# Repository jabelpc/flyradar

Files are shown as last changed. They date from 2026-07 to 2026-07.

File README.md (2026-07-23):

# 📡 FlyRadar

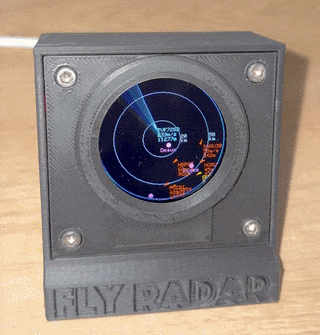
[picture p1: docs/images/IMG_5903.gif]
FlyRadar GIF


FlyRadar est un fork du projet micro-radar d'AnthonySturdy (https://github.com/AnthonySturdy/micro-radar). J'ai adapté le projet au matériel dont je disposais et ajouté des options de personnalisation ainsi qu'une mise à jour du firmware par OTA (téléversement over-the-air).

## Matériel

Le projet fonctionne avec un ESP32-C3 (super-mini) et un écran LCD 1,28" (GC9A01). Selon votre montage, quelques fils devront être soudés ou connectés avec des câbles Dupont.

Pour le boîtier, j'ai imprimé les pièces en PLA. L'écran et la carte sont fixés à la colle chaude ; des vis M3x15 peuvent être ajoutées pour la finition.

### Outils nécessaires

- Clé Allen 2,5 mm
- Pistolet à colle chaude
- Fer à souder (si vous choisissez l'option soudure)

Attention : l'écran est fragile et sensible aux rayures.

### Liste de composants (exemples)

- Écran 1.28" Round GC9A01 (IPS)
- Carte ESP32-C3 (super-mini)
- 4 vis M3x15

Toute carte ESP32 peut convenir, mais le câblage peut différer selon le modèle et doit être adapté.

### Câblage (exemple)

ESP32-C3 // LCD GC9A01

- 3V3 → VCC
- GND → GND
- GPIO4 → SCL
- GPIO5 → SDA
- GPIO9 → DC
- GPIO6 → CS
- GPIO3 → RST

<p align="center">
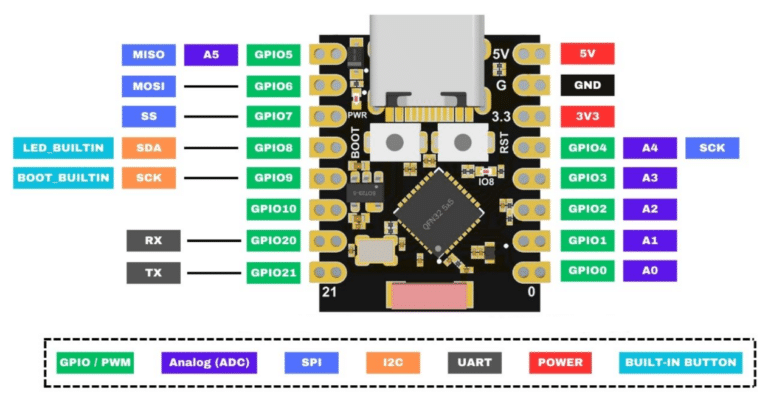
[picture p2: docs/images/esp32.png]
  
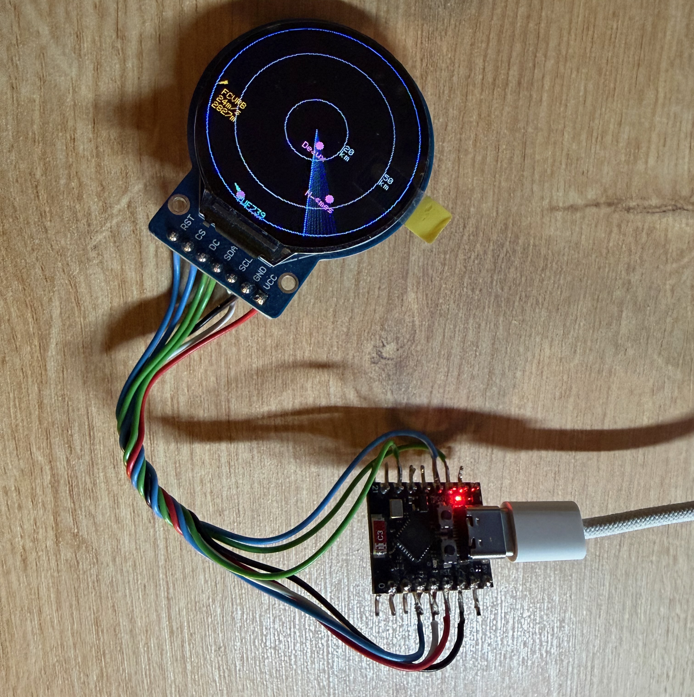
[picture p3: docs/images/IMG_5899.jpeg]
  
</p>

## Comptes / API

Ce projet peut utiliser l'API OpenSky pour récupérer les données de vol. Créer un compte OpenSky est recommandé (gratuit) : le quota de requêtes passe d'environ 400 à ~4000 par jour, améliorant la précision et la réactivité de l'affichage en direct. Inscrivez-vous sur https://opensky-network.org.

## Développement et téléversement

Installez Visual Studio Code et l'extension PlatformIO IDE. Ouvrez le projet dans VS Code ; PlatformIO installera automatiquement les dépendances.

Branchez la carte via USB-C et téléversez depuis PlatformIO (bouton Upload). Si la carte ne redémarre pas automatiquement, maintenez `BOOT`, appuyez sur `RESET`, puis relâchez `BOOT`.

## Premier démarrage

Au premier démarrage, la carte diffuse un point d'accès Wi‑Fi `FlyRadar-Setup`. Connectez-vous avec un appareil (téléphone ou ordinateur) : la page de configuration s'ouvrira automatiquement. Renseignez votre Wi‑Fi et sauvegardez : la carte redémarrera et se connectera au réseau.

Si le point d'accès n'apparaît pas immédiatement, attendez 30 secondes et réessayez.

## Configuration

Une fois connecté au réseau, la configuration est accessible depuis n'importe quel appareil à l'adresse : http://flyradar.local

Options disponibles :

- **Position** : latitude / longitude (centre du radar)
- **Rayon du radar** : angle de balayage (en degrés)
- **Options d'affichage** : activer/désactiver certains éléments visuels

Si vous avez un compte OpenSky, renseignez vos identifiants dans la configuration pour bénéficier du quota étendu.

## Remarques

- Ce projet a été réalisé comme un projet personnel et s'inspire de plusieurs créations.

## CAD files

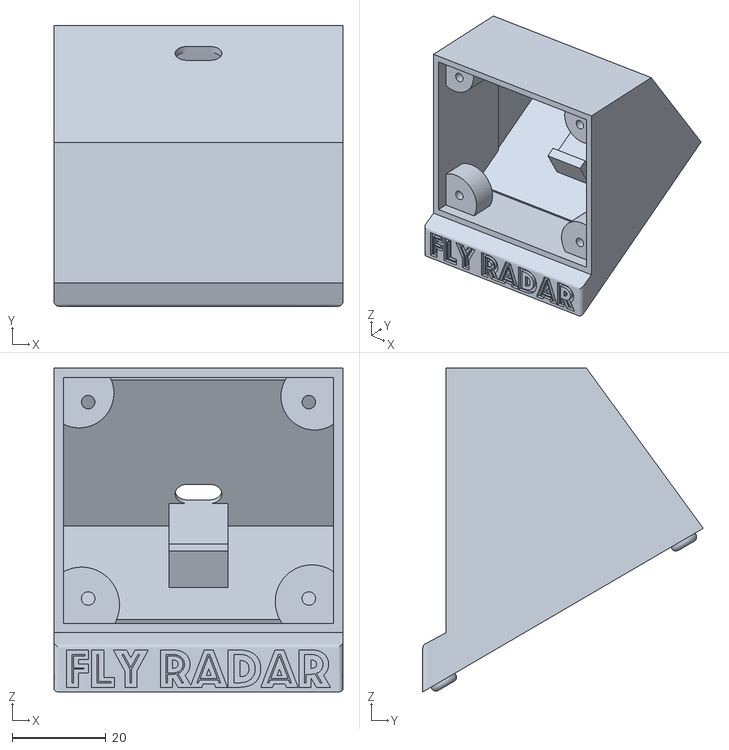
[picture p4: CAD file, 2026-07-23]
hardware/stl/Base 2 v3.stl
61.8 x 60.0 x 69.3

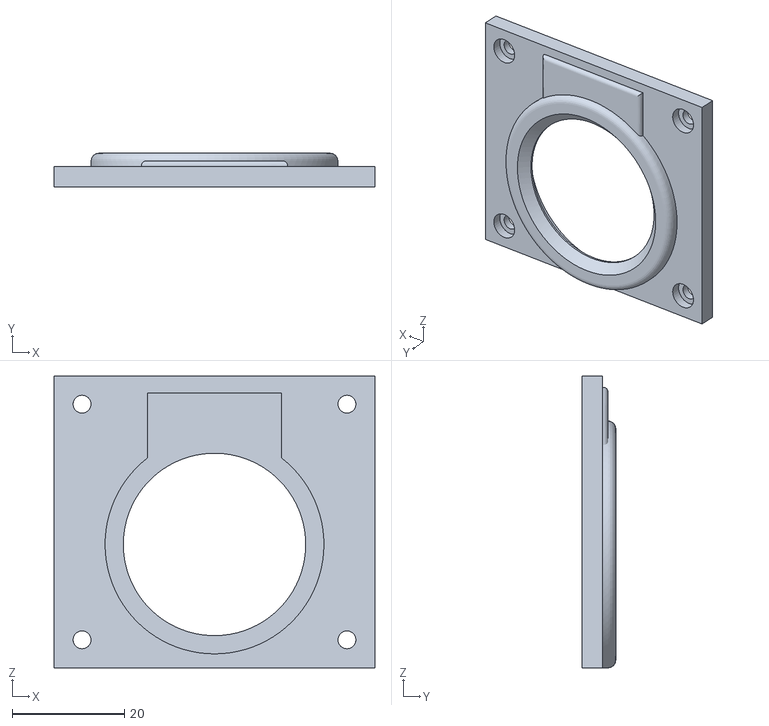
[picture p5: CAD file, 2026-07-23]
hardware/stl/porte écran v3.stl
57.2 x 6.00 x 52.0

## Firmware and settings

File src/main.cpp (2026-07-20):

#include <Arduino.h>
#include <ArduinoJson.h>
#include <WiFiManager.h>
#include <ArduinoOTA.h>

#include "LGFX.h"
#include "WiFiManagerHelpers.h"
#include "ConfigurationWebServer.h"
#include "HttpRequestManager.h"
#include "OpenSkyAuthTokenHandler.h"
#include "AircraftManager.h"
#include "DrawHelpers.h"
#include "ColorTheme.h"
#include "models/Aircraft.h"
#include "models/TrackedAircraft.h"

// Optional hard-coded Wi-Fi credentials. Leave both blank to skip pre-baking them and use the setup hotspot instead.
const char* preconfiguredWifiSsid = "";
const char* preconfiguredWifiPassword = "";

constexpr int SCREEN_SIZE = 240;
constexpr int SCREEN_SIZE_DIV_2 = (SCREEN_SIZE / 2);

LGFX tft;
LGFX_Sprite backbuffer(&tft);

WiFiManager wm;
ConfigurationWebServer configServer;
HttpRequestManager http;
OpenSkyAuthTokenHandler authHandler(http);

AircraftManager aircraftManager(configServer, authHandler, http, tft);

static void SetupOTA()
{
  ArduinoOTA.setHostname("flyradar");

  ArduinoOTA.onStart([]() {
    Serial.println("[OTA] Start");
  });

  ArduinoOTA.onEnd([]() {
    Serial.println("[OTA] End");
  });

  ArduinoOTA.onError([](ota_error_t error) {
    Serial.printf("[OTA] Error[%u]: ", error);
    if (error == OTA_AUTH_ERROR) Serial.println("Authentication Failed");
    else if (error == OTA_BEGIN_ERROR) Serial.println("Begin Failed");
    else if (error == OTA_CONNECT_ERROR) Serial.println("Connect Failed");
    else if (error == OTA_RECEIVE_ERROR) Serial.println("Receive Failed");
    else if (error == OTA_END_ERROR) Serial.println("End Failed");
  });

  ArduinoOTA.begin();
  Serial.println("[OTA] Ready");
  Serial.print("[OTA] IP: ");
  Serial.println(WiFi.localIP());
}

void setup()
{
  Serial.begin(115200);
  // delay(1000); // avoids immediate serial output being cut off - uncomment if needed

  // initialise LGFX + screen
  tft.init();
  tft.invertDisplay(true);
  // Note : pas de digitalWrite manuel ici. Sur le montage d'origine, le GPIO3
  // pilotait le rétro-éclairage. Ici, le GPIO3 est câblé au RST de l'écran
  // (géré en interne par LovyanGFX via cfg.pin_rst) et le rétro-éclairage
  // (BLK) est câblé directement en 3V3.

  backbuffer.setColorDepth(8);
  backbuffer.createSprite(SCREEN_SIZE, SCREEN_SIZE);

  // establish WiFi connection
  const RadarTheme bootTheme = ParseTheme(configServer.GetStoredString("theme"));
  tft.fillScreen(lgfx::color888(0, 0, 0));
  tft.setTextColor(ThemeBaseColor(bootTheme, 255));
  tft.drawCentreString("Connecting to WiFi...", SCREEN_SIZE / 2, SCREEN_SIZE / 2);

  WiFiManagerHelpers::ConfigureWiFiManager(wm, tft);

  if (strlen(preconfiguredWifiSsid) > 0) {
    WiFi.begin(preconfiguredWifiSsid, preconfiguredWifiPassword);
    WiFi.waitForConnectResult();
  }

  wm.autoConnect(WiFiManagerHelpers::WiFiManagerName);

  // enable OTA updates over WiFi
  SetupOTA();

  // begin background server for configuration
  configServer.Initialise();

  // initialise aircraft manager
  aircraftManager.Initialise();
}

void loop()
{
  ArduinoOTA.handle();
  aircraftManager.Update();

  // draw cycle
  backbuffer.fillScreen(lgfx::color888(0, 0, 0));

  String renderScanlines = configServer.GetStoredString("scanline");
  if (renderScanlines.isEmpty() || renderScanlines == "true") {
    DrawScanLines(backbuffer,
      SCREEN_SIZE_DIV_2 - 1,
      SCREEN_SIZE_DIV_2 - 1,
      SCREEN_SIZE_DIV_2 - 1 + (std::cos(millis() / 3000.0f) * SCREEN_SIZE_DIV_2),
      SCREEN_SIZE_DIV_2 - 1 + (std::sin(millis() / 3000.0f) * SCREEN_SIZE_DIV_2),
      20, 128, 5,
      aircraftManager.GetTheme()
    );
  }

  aircraftManager.Draw(backbuffer);
  backbuffer.pushSprite(0, 0);
}

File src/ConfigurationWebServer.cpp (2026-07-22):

#include "ConfigurationWebServer.h"
#include <ArduinoJson.h>
#include <ESPmDNS.h>
#include <HTTPClient.h>
#include <Update.h>

static constexpr const char* GitHubOwner = "jabelpc";
static constexpr const char* GitHubRepo = "flyradar";
static constexpr const char* GitHubBinAssetName = "flyradar.bin";
static constexpr const char* GitHubUserAgent = "FlyRadarOTA/1.0";
static constexpr const char* CurrentFirmwareVersion = "1.0.1";

struct GitHubReleaseInfo {
    bool success;
    String latestVersion;
    String downloadUrl;
    String errorMessage;
};

static String NormalizeVersion(String version)
{
    if (version.startsWith("v") || version.startsWith("V")) {
        return version.substring(1);
    }
    return version;
}

static int CompareVersions(const String& a, const String& b)
{
    const String normalizedA = NormalizeVersion(a);
    const String normalizedB = NormalizeVersion(b);

    int indexA = 0;
    int indexB = 0;
    while (indexA < normalizedA.length() || indexB < normalizedB.length()) {
        int nextDotA = normalizedA.indexOf('.', indexA);
        int nextDotB = normalizedB.indexOf('.', indexB);

        if (nextDotA == -1) nextDotA = normalizedA.length();
        if (nextDotB == -1) nextDotB = normalizedB.length();

        const String partA = normalizedA.substring(indexA, nextDotA);
        const String partB = normalizedB.substring(indexB, nextDotB);

        const int valueA = partA.toInt();
        const int valueB = partB.toInt();

        if (valueA < valueB) return -1;
        if (valueA > valueB) return 1;

        indexA = nextDotA == normalizedA.length() ? normalizedA.length() : nextDotA + 1;
        indexB = nextDotB == normalizedB.length() ? normalizedB.length() : nextDotB + 1;
    }

    return 0;
}
static GitHubReleaseInfo FetchLatestGithubRelease()
{
    // If the repo owner/repo are left as placeholders, return a clear error
    if (String(GitHubOwner) == "your-github-owner" || String(GitHubRepo) == "your-github-repo") {
        return {false, "", "", "GitHub owner/repo not configured. Set GitHubOwner and GitHubRepo in ConfigurationWebServer.cpp"};
    }
    HTTPClient http;
    const String apiUrl = String("https://api.github.com/repos/") + GitHubOwner + "/" + GitHubRepo + "/releases/latest";
    http.begin(apiUrl);
    http.addHeader("User-Agent", GitHubUserAgent);
    http.addHeader("Accept", "application/vnd.github+json");
    http.setFollowRedirects(HTTPC_STRICT_FOLLOW_REDIRECTS);

    const int responseCode = http.GET();
    if (responseCode != HTTP_CODE_OK) {
        const String errorMessage = String("GitHub API error: ") + responseCode;
        http.end();
        return {false, "", "", errorMessage};
    }

    const String payload = http.getString();
    Serial.println(String("[OTA] GitHub response length: ") + payload.length());
    if (payload.isEmpty()) {
        Serial.println("[OTA] GitHub payload is empty");
    }
    http.end();

    DynamicJsonDocument doc(8192);
    const DeserializationError parseError = deserializeJson(doc, payload);
    if (parseError) {
        Serial.println(String("[OTA] GitHub JSON parse error: ") + parseError.c_str());
        Serial.println(String("[OTA] GitHub payload: ") + payload);
        String errorMessage = String("JSON parse error: ") + parseError.c_str();
        errorMessage += String("; length=") + payload.length();
        if (!payload.isEmpty()) {
            errorMessage += String("; data=\"") + payload.substring(0, 120) + "\"";
        }
        return {false, "", "", errorMessage};
    }

    const String latestVersion = doc["tag_name"].as<String>();
    if (latestVersion.isEmpty()) {
        return {false, "", "", "GitHub release tag not found"};
    }

    const JsonArray assets = doc["assets"].as<JsonArray>();
    if (assets.isNull()) {
        return {false, latestVersion, "", "No release assets found"};
    }

    for (const JsonObject asset : assets) {
        const String name = asset["name"].as<String>();
        if (name == GitHubBinAssetName) {
            const String downloadUrl = asset["browser_download_url"].as<String>();
            return {true, latestVersion, downloadUrl, ""};
        }
    }

    return {false, latestVersion, "", String("No asset named '") + GitHubBinAssetName + "' found"};
}
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

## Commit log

2026-07-20 Initial commit: rename to flyradar and add OTA GitHub support
    [Bezel.stl, Board clamp washer.stl, Case and mounting points.stl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]
2026-07-22 Publish configuration UI and OTA update fixes
    [ConfigurationWebServer.cpp]
2026-07-23 Publish docs and reorganize hardware assets for GitHub
    [Base 2 v3.stl, Bezel.stl, Board clamp washer.stl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]
2026-07-23 Publish current README
